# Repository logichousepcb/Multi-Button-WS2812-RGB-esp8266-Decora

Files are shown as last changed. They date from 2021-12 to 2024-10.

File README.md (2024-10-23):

# Multi-Button-WS2812-RGB-esp8266-Decora
Multi Button WS2812 RGB esp8266 Decora <br>
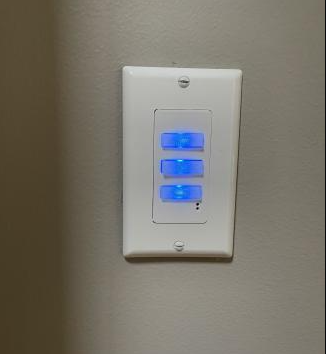
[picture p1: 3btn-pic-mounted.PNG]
<br>
This project is a multi button RGB scene cotroller that fits a decora faceplate.  This initial project built on previous projects after digiblur suggested some ideas.  Using my already built template for creating devices that fit into a decora faceplate I set out to create thiis open hardware.  I have plans to create a few different version but I figure I would start with this 3 button version to prove the concept and built off of.

Thanks to digiblur and all the members of the projects-and-shares channel on his discord server for suggestions, help and inspiration. <br>

<br>
For a prebuilt controller or just the bare circuit board, visit my store at https://logixdiy.com/ and select board only for a bare board.<br>
<br>
I have included some basic esphome yaml for this switch. <br>
<br>
Tasmota Template and instructions <br>

For the ESP-12F version here is the template<br>

{"NAME":"Logix3","GPIO":[1,1,1,1,32,33,1,1,1376,34,1312,1,1,1],"FLAG":0,"BASE":18} <br>

For the ESP-C3-12F version use the one bellow as the pinout are different <br>

{"NAME":"Logix3-C3","GPIO":[1,1,1,1312,1376,32,0,1,1,1,1,0,0,0,0,0,0,0,34,33,1,1],"FLAG":0,"BASE":1} <br>
<br>
For the ESP-C3-12F 6 Button version with PIR and Temperature use the one bellow as the pinout are different <br>
{"NAME":"Logix6-C3","GPIO":[1,1,35,1376,32,166,34,33,1,1,36,0,0,0,0,0,0,0,1312,37,1,1],"FLAG":0,"BASE":1}
<br>
Here is a list of options I have configured on my device<br>
<br>
Led<x>	#RRGGBB = set hex color value where <x> is the pixel number of the LED. A blank-delimited list of colors sets multiple successive pixels. <br>
<br>
SetOption1 1 - turn off multi press to prevent accidental long press reset<br>
<br>
SetOption8 1 -	Show temperature in (0= Celsius (default) 1 = Fahrenheit)<br>
 <br>
SetOption73	1 - Detach buttons from relays and send multi-press and hold MQTT messages instead (0 = disable (default) 1 = enable) <br>
<br>
SetOption65	1 - Device recovery using fast power cycle detection (0 = enabled (default) 1 = disabled)<br>
<br>
TempOffset XX - where XX is a number from -12.6..12.6 as these dallas temp sensors aren't known for their accuracy<br>
 3D Printing<br>
 <br>
 <a href="https://www.buymeacoffee.com/logixpcbM" target="_blank">Buy Me A Coffee</a> <br>
 
 Print the back cover in the color of your choice<br>
 Print 3 buttons in clear PLA (white works in a pinch)<br>
 Print the Decora face in white (or whatever you like)<br>
 Print the Light Blocker in black or a dark color<br>
 <br>
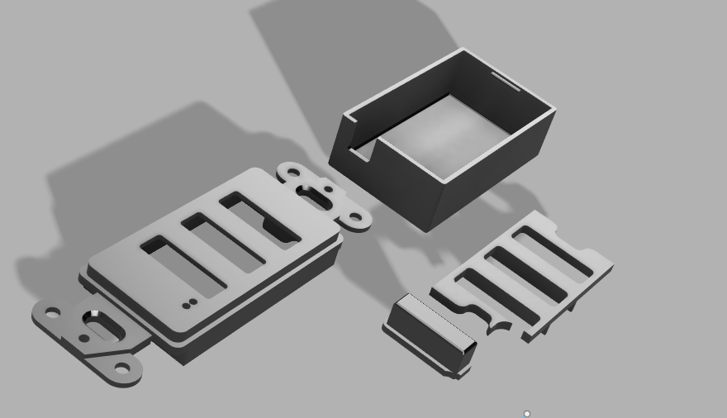
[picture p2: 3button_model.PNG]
 <br>
 
 <br>

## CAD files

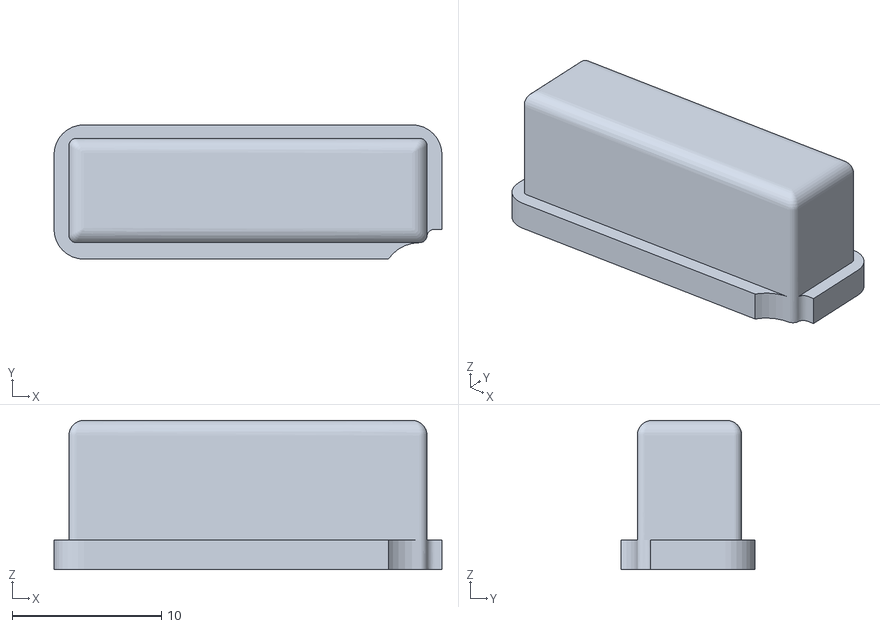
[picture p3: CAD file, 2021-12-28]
3Button_Single_Button.stl
26.0 x 9.00 x 10.0

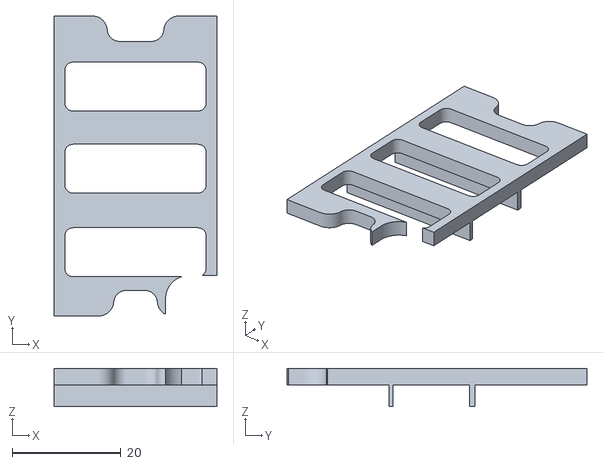
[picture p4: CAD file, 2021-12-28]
3Button_Light_Block.stl
29.9 x 55.2 x 7.00

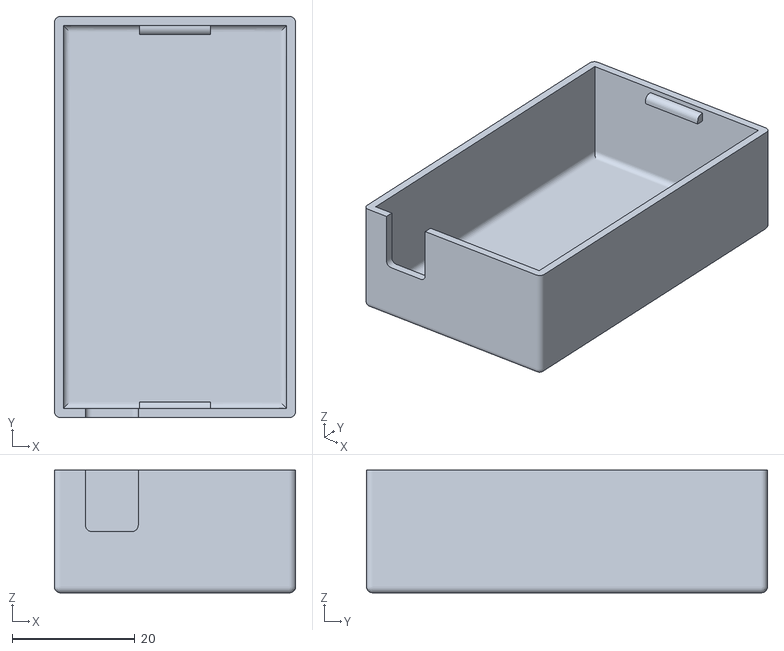
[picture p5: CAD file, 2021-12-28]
3Button_Back .stl
39.4 x 65.4 x 20.0

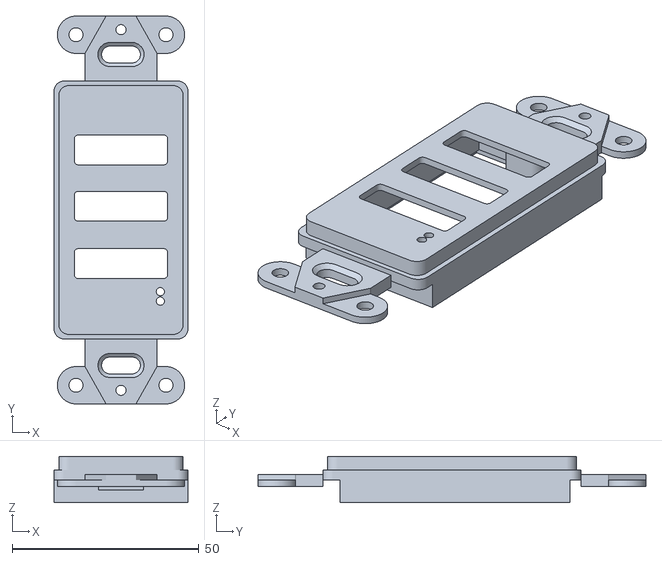
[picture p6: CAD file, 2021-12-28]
3Button_Front.stl
35.9 x 103.9 x 12.3

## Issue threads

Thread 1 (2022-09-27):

Parts links

marc-gist, 2022-09-27:
Thank you for sharing! I'm looking at building some of these. Would you mind sharing links to the parts so that I ensure I get the correct size? notably the SMD ones.  Perhaps some photos as well.

Thank you!

logichousepcb, 2022-09-28:
Have you already ordered some pcb’s?  I have a never version. I can send you a parts list if I know which version you plan to build.

Sent from Mike's iPhone

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

marc-gist, 2022-09-28:
I did order from the gerber's found here. I'm happy to order some of a new version too :)  I have most parts, but want to ensure I have/order correct size for the SMD.  I have some ESP32-C3-12F i may try on it as well.
Thanks!

logichousepcb, 2022-09-28:
I’ll check it out later after work. I can’t remember which I posted there. I have 5 iterations of it. I do have some I c3 swapped.  I have a 6 button version with temp and motion as well.

Sent from Mike's iPhone

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

logichousepcb, 2022-09-28:
This is the button I used but there is also a thinner version that works
depending on the 3d printer button used.
https://www.amazon.com/gp/product/B07H9R9YMJ/ref=ppx_yo_dt_b_search_asin_title?ie=UTF8&psc=1

The AMS1117 is a standard 3.3 version

I used these leds but they are a standard size so a 5v ws2812 will work
since these are discontinued
https://www.lcsc.com/product-detail/Light-Emitting-Diodes-LED_Worldsemi-WS2812E_C139127.html

The resistors are 1206 size
10k and 4.7k

C4 =
https://www.lcsc.com/product-detail/Aluminum-Electrolytic-Capacitors-SMD_ROQANG-RVT1C100M0405_C72483.html
C3 =
https://www.lcsc.com/product-detail/Aluminum-Electrolytic-Capacitors-SMD_KNSCHA-RVT100UF10V67RV0036_C2891567.html

I hope that works.  Let me know if you have any questions

On Wed, Sep 28, 2022 at 8:06 AM Michael Degenaars ***@***.***>
wrote:

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

logichousepcb, 2022-09-29:
It’s bellow the esp-12f template in the github page.

Sent from Mike's iPhone

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

Closed 2024-09-23.
